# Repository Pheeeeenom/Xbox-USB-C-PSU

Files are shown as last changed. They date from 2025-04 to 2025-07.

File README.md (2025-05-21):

# Xbox-USB-C-PSU
The first ever USB C PSU for the original Xbox

# NOTE:
This board currently supports all 3 Xbox motherboard revisions, but requires a different BOM for 009 and 012 than 121.
If you don't know what revision your Xbox is, you can find out with this guide: [https://www.herringhardware.com/xboxrevisions](https://www.herringhardware.com/XboxRevisions.html)

# REPO STRUCTURE:
All source files for the PCB are contained within the respective folder for each of the 3 official Xbox PCB revions,
-121 to start with, and -009 and -012 will be added soon.
Production files to manufacture the PCBs are located in [Releases](https://github.com/Redherring32/Xbox-USB-C-PSU/releases)

# PCB SPECS:
* 4 layers
* 151.739x39.78mm
* 1oz copper (all layers), heat issues may result from skimping on this
* filled vias (VIPPO) for assembly reasons due to via in pad

kicad_rvZLV58yR5

## LICENSE:
Licensed under
the TAPR Open hardware license (www.tapr.org/OHL)

©Redherring32 2025

## DISCLAIMER:
I offer this with no warranty, express or implied, and I am NOT responsible for anything that may happen as a result of misuse of this PCB.
You have been warned.

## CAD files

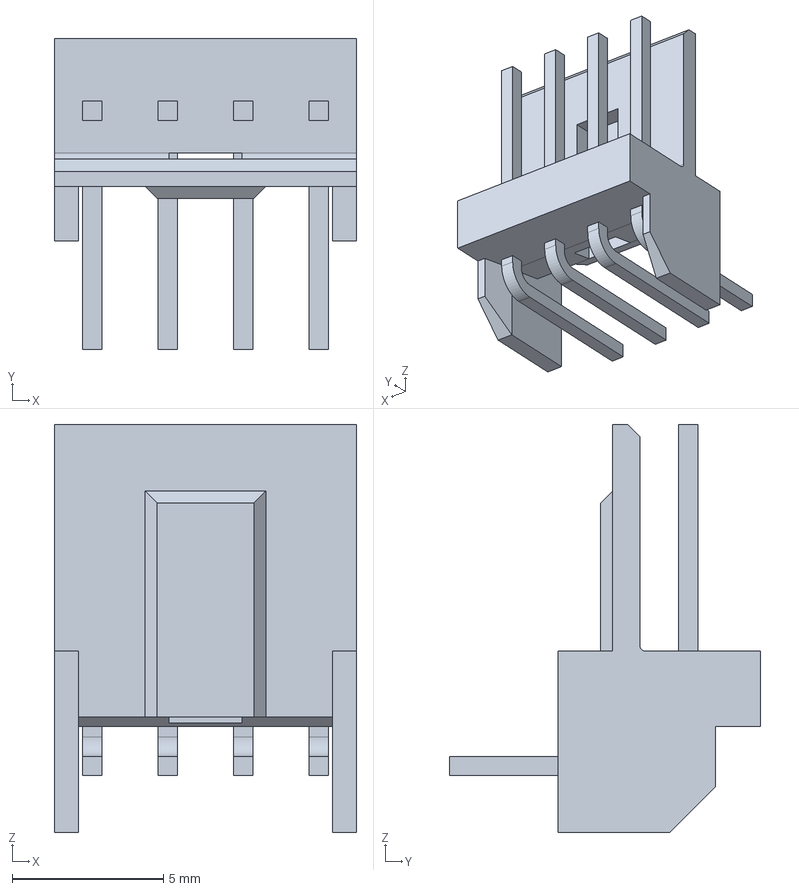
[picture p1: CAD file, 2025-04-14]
-009_012/3D/c-171826-4-y3-3d.stp
10.0 x 10.3 x 13.5 mm

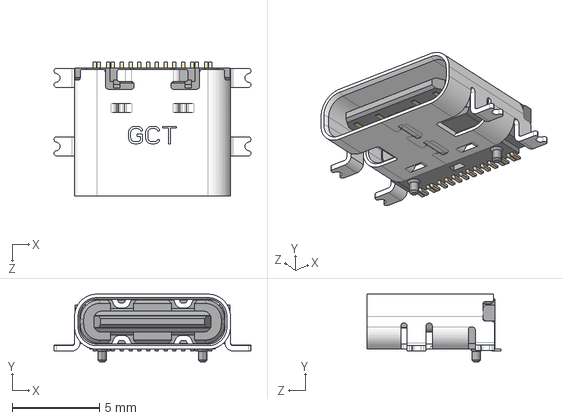
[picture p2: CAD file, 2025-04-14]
-009_012/3D/USB4110GFA.step
11.3 x 3.89 x 7.70 mm

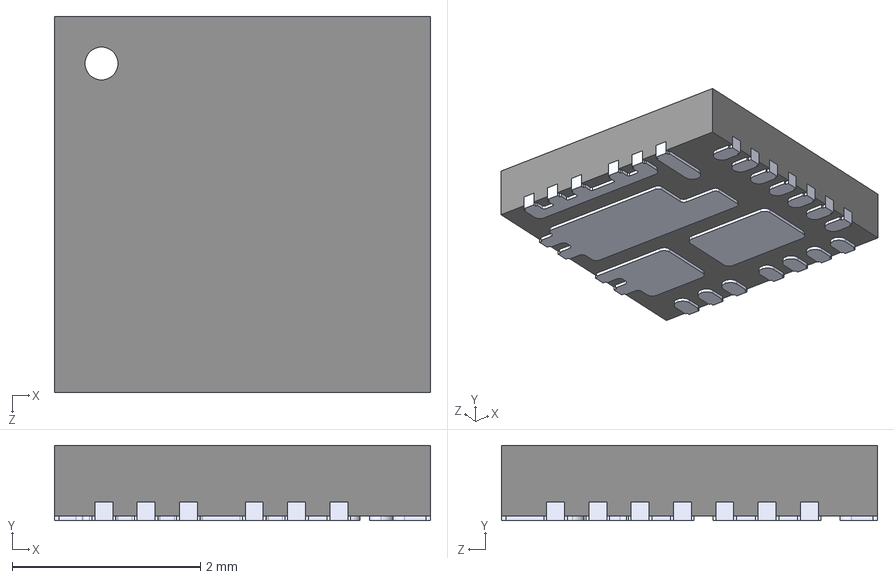
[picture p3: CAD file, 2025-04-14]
-009_012/3D/SIC437BED-T1-GE3.STEP
4.00 x 0.8 x 4.00 mm

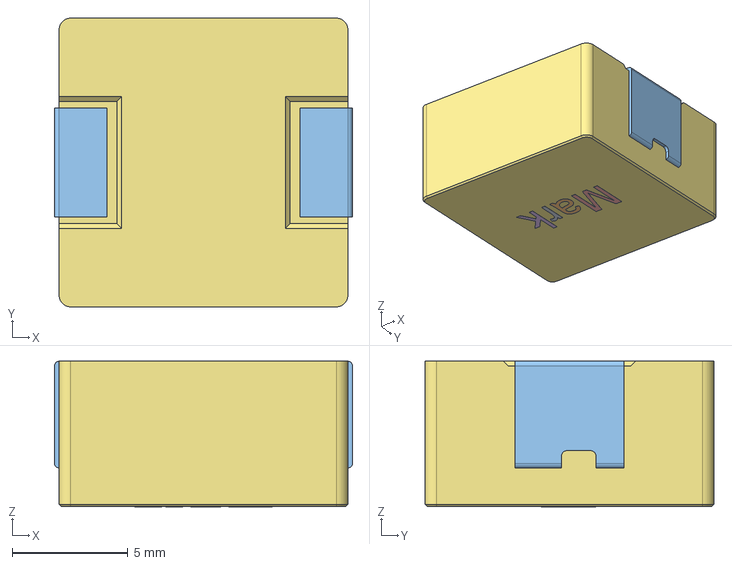
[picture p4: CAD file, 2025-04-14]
-009_012/3D/SRP1265A series.stp
12.9 x 12.5 x 6.30 mm

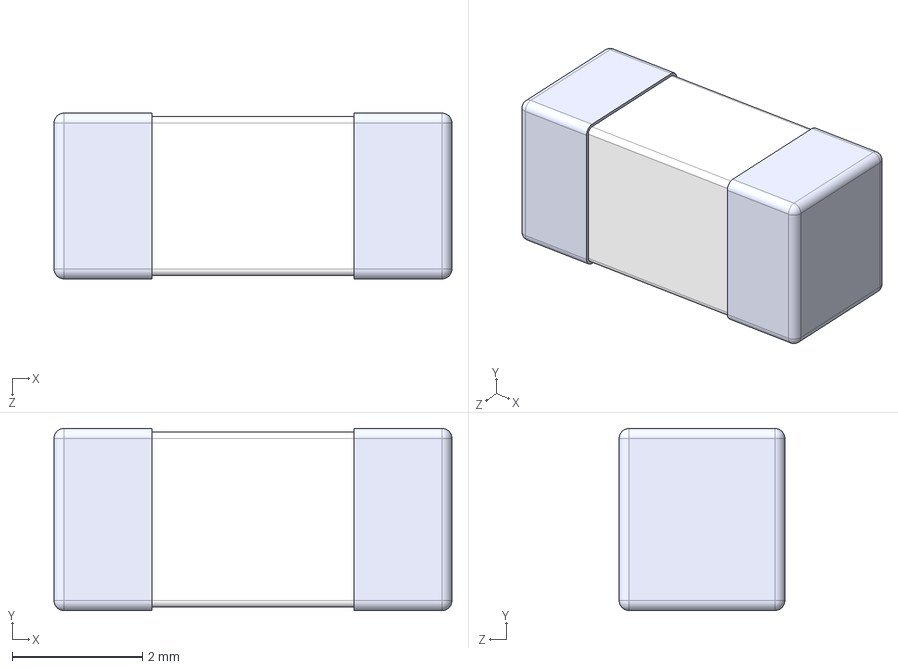
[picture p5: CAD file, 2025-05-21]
-009_012/3D/0679H5000-01.stp
6.10 x 2.79 x 2.54 mm

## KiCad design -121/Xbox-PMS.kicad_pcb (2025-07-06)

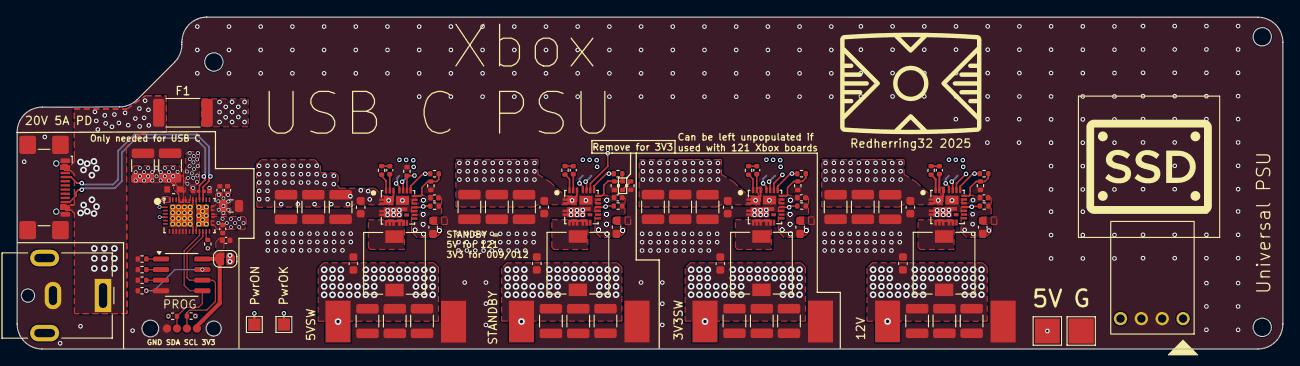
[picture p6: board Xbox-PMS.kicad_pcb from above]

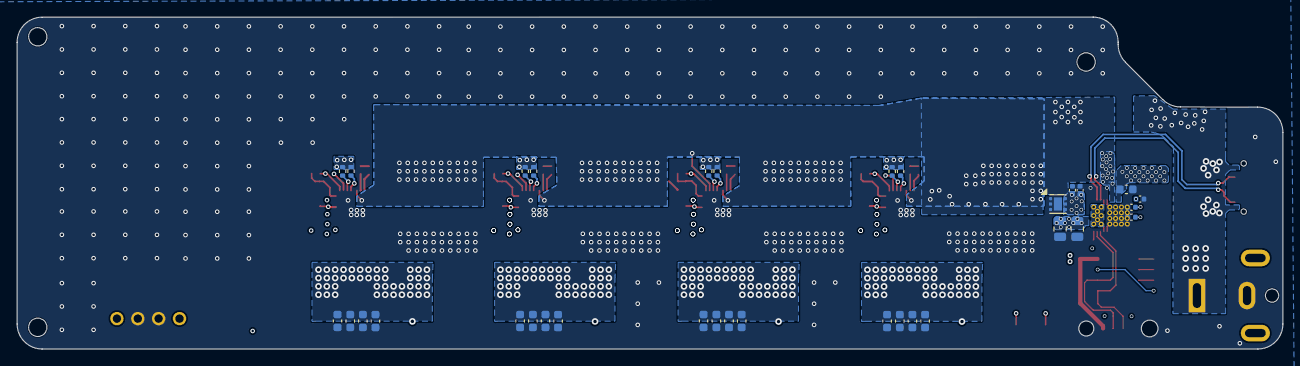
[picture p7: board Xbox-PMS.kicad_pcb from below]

Board: 4 copper layers, 151.7 x 39.8 mm, 139 parts (33 on the bottom side), 55 nets.

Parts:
C1, C2, C3, C4, C5, C6, C8, C10, C11, C64, C65, C66: 22uF; C_1210_3225Metric
C7, C9, C13, C30, C31, C33, C34, C35, C36, C37, C38, C39, C40, C41, C44, C67, C74, C75, C76, C77: 22uF; C_0603_1608Metric
C12, C14, C16, C68: 1uF; C_0402_1005Metric
C15, C17, C18, C69: 4.7uF; C_0603_1608Metric
C19, C20, C22, C60, C70: 0.1uF; C_0402_1005Metric
C21, C23, C24, C25, C26, C27, C28, C29, C32, C71, C72, C73: 47uF; C_1210_3225Metric
C42, C43, C45, C78: 0.1uF; C_0603_1608Metric
C46, C49: 100uF 16V; C_1210_3225Metric
C47: 4.7uF 50V; C_0805_2012Metric
C48, C50, C52, C54, C61: 0.1uF 50V; C_0402_1005Metric
C51, C53: 10uF 16V; C_0603_1608Metric
C55, C56, C57: 10uF 16V; C_0402_1005Metric
C58, C59: 22uF 50V; C_0805_2012Metric
C62, C63: 330pF 16V; C_0201_0603Metric
F1: Fuse 5A; Fuse_2512_6332Metric
IC1, IC2, IC3, IC4: SIC437BED-T1-GE3; SIC437BEDT1GE3
J2: USB_C_Receptacle_USB2.0_16P; USB_C_Receptacle_GCT_USB4110
J3: Jack-DC; BarrelJack_CUI_PJ-063AH_Horizontal
J6: Conn_01x04_Pin; PROG
J7: Conn_01x04_Pin; FDD Connector
J8, J9: Conn_01x01_Pin; TestPoint_Pad_1.5x1.5mm
JP1: Jumper_2_Open; SolderJumper-2_P1.3mm_Open_RoundedPad1.0x1.5mm
L1, L3: 780nH; L_7.3x7.3_H4.5
L2, L4: 820nH; L_7.3x7.3_H4.5
R1, R2, R7, R10, R11, R12, R21, R24, R25, R26, R27: 10K; R_0402_1005Metric
R3, R5, R8, R28: 100K; R_0402_1005Metric
R4, R6, R9, R29: 499K; R_0402_1005Metric
R13, R16, R19, R31: 2.2R; R_0402_1005Metric
R14: 45K; R_0402_1005Metric
R15, R18: 4.12K; R_0402_1005Metric
R17, R20: 18.7K; R_0402_1005Metric
R22, R23: 2.2K; R_0402_1005Metric
R30: 430R; R_0402_1005Metric
R32: 8.2K; R_0402_1005Metric
R35: 6.8K; R_0402_1005Metric
R36: 0; R_0402_1005Metric
TP3, TP4, TP5, TP6, TP7, TP8, TP9, TP10: TestPoint; pad
U1: TVS2200DRV; WSON-6-1EP_2x2mm_P0.65mm_EP1x1.6mm
U2: TPS25750; TPS25750D
U3: CAT24C512; SOIC-8_3.9x4.9mm_P1.27mm

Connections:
/3V3: C57.1, U2.38 (VIN_3V3)
/3V3SB: C23.2, C25.1, C28.1, C31.1, C34.1, C37.1, C40.1, C43.1, IC1.18 (VOUT), L2.2, R17.1, TP5.1
/3V3SW: C21.2, C24.1, C27.1, C30.1, C33.1, C36.1, C39.1, C42.1, IC2.18 (VOUT), L1.2, R14.1, TP3.1
/5VSW: C26.2, C29.1, C32.1, C35.1, C38.1, C41.1, C44.1, C45.1, IC3.18 (VOUT), J7.4, L3.2, R20.1, TP7.1
/12V: C71.2, C72.1, C73.1, C74.1, C75.1, C76.1, C77.1, C78.1, IC4.18 (VOUT), J7.1, L4.2, R32.1, TP9.1
/CCx+: C63.1, J2.A5 (CC1), U2.28 (CC1)
/CCx-: C62.1, J2.B5 (CC2), U2.29 (CC2)
/DRAIN: U2.15 (DRAIN), U2.30 (DRAIN), U2.40 (DRAIN_PAD)
/EEPROM_3V3: C60.1, J6.4, JP1.1 (A), U3.8 (VCC)
/EN: IC2.19 (EN), IC3.19 (EN), IC4.19 (EN), J9.1, R11.1
/LDO_1V5: C56.1, U2.4 (LDO_1V5)
/LDO_3V3: C55.1, JP1.2 (B), R21.2, R22.2, R23.2, U2.1 (LDO_3V3)
/PGOOD: IC1.14 (P_GOOD), IC2.14 (P_GOOD), IC3.14 (P_GOOD), IC4.14 (P_GOOD), J8.1, R1.1, R2.1, R7.1, R10.1
/PP5V: C46.1, C49.1, C51.1, C53.1, U2.34 (PP5V), U2.35 (PP5V)
/PPHV: C58.1, C59.1, C61.1, U2.20 (PPHV), U2.21 (PPHV), U2.22 (PPHV)
/SCL: J6.3, R23.1, U2.17 (I2Cm_SCL), U3.6 (SCL)
/SDA: J6.2, R22.1, U2.16 (I2Cm_SDA), U3.5 (SDA)
/VBUS-IN: F1.1, J2.A4 (VBUS), J2.A9 (VBUS), J2.B4 (VBUS), J2.B9 (VBUS), J3.1
/VBUS-SAFE: C1.1, C2.1, C3.1, C4.1, C5.1, C6.1, C7.1, C8.1, C9.1, C10.1, C11.1, C13.1, C47.1, C48.1, C50.1, C52.1, C54.1, C64.1, C65.1, C66.1, C67.1, F1.2, IC1.1 (VIN), IC1.2 (VIN), IC1.19 (EN), IC1.22 (VIN), IC1.26 (VIN), IC2.1 (VIN), IC2.2 (VIN), IC2.22 (VIN), IC2.26 (VIN), IC3.1 (VIN), IC3.2 (VIN), IC3.22 (VIN), IC3.26 (VIN), IC4.1 (VIN), IC4.2 (VIN), IC4.22 (VIN), IC4.26 (VIN), U1.4 (IN), U1.5 (IN), U1.6 (IN), U2.23 (VBUS_IN), U2.24 (VBUS_IN), U2.25 (VBUS_IN), U2.32 (VBUS), U2.33 (VBUS)
/VDD: C12.2, C14.2, C15.2, C16.2, C17.2, C18.2, C68.2, C69.2, IC1.12 (V_DRV), IC1.15 (VDD), IC2.12 (V_DRV), IC2.15 (VDD), IC3.12 (V_DRV), IC3.15 (VDD), IC4.12 (V_DRV), IC4.15 (VDD), R1.2, R2.2, R3.2, R4.1, R5.2, R6.1, R7.2, R8.2, R9.1, R10.2, R28.2, R29.1
/~IRQ: R21.1, U2.18 (I2Cm_IRQ_N)
GND: C1.2, C2.2, C3.2, C4.2, C5.2, C6.2, C7.2, C8.2, C9.2, C10.2, C11.2, C12.1, C13.2, C14.1, C15.1, C16.1, C17.1, C18.1, C21.1, C23.1, C24.2, C25.2, C26.1, C27.2, C28.2, C29.2, C30.2, C31.2, C32.2, C33.2, C34.2, C35.2, C36.2, C37.2, C38.2, C39.2, C40.2, C41.2, C42.2, C43.2, C44.2, C45.2, C46.2, C47.2, C48.2, C49.2, C50.2, C51.2, C52.2, C53.2, C54.2, C55.2, C56.2, C57.2, C58.2, C59.2, C60.2, C61.2, C62.2, C63.2, C64.2, C65.2, C66.2, C67.2, C68.1, C69.1, C71.1, C72.2, C73.2, C74.2, C75.2, C76.2, C77.2, C78.2, IC1.3 (PGND), IC1.4 (PGND), IC1.13 (PGND), IC1.16 (AGND), IC1.25 (AGND), IC1.27 (PGND), IC1.29 (PGND), IC2.3 (PGND), IC2.4 (PGND), IC2.13 (PGND), IC2.16 (AGND), IC2.25 (AGND), IC2.27 (PGND), IC2.29 (PGND), IC3.3 (PGND), IC3.4 (PGND), IC3.13 (PGND), IC3.16 (AGND), IC3.25 (AGND), IC3.27 (PGND), IC3.29 (PGND), IC4.3 (PGND), IC4.4 (PGND), IC4.13 (PGND), IC4.16 (AGND), IC4.25 (AGND), IC4.27 (PGND), IC4.29 (PGND), J2.A1 (GND), J2.A12 (GND), J2.B1 (GND), J2.B12 (GND), J2.S1 (SHIELD), J3.2, J6.1, J7.2, J7.3, R11.2, R12.2, R15.2, R18.2, R24.2, R25.2, R26.2, R27.2, R30.2, R35.2, TP4.1, TP6.1, TP8.1, TP10.1, U1.1 (GND), U1.2 (GND), U1.3 (GND), U1.7 (GND), U2.8 (I2Cs_SDA), U2.9 (I2Cs_SCL), U2.10 (I2Cs_IRQ_N), U2.11 (GND), U2.12 (GND), U2.14 (GND), U2.31 (GND), U2.39 (GND_PAD), U3.4 (GND)
unnamed: C19.2, R13.2
unnamed: C20.2, R16.2
unnamed: C22.2, R19.2
unnamed: C70.2, R31.2
unnamed: C20.1, IC1.23 (BOOT)
unnamed: IC1.17 (FB), R15.1, R17.2
unnamed: IC1.21 (MODE1), R5.1
unnamed: IC1.20 (MODE2), R6.2
unnamed: IC1.24 (PHASE), R16.1
unnamed: IC1.5 (SW), IC1.6 (SW), IC1.7 (SW), IC1.8 (SW), IC1.9 (SW), IC1.30 (SW), L2.1
unnamed: C19.1, IC2.23 (BOOT)
unnamed: IC2.17 (FB), R12.1, R14.2
unnamed: IC2.21 (MODE1), R3.1
unnamed: IC2.20 (MODE2), R4.2
unnamed: IC2.24 (PHASE), R13.1
unnamed: IC2.5 (SW), IC2.6 (SW), IC2.7 (SW), IC2.8 (SW), IC2.9 (SW), IC2.30 (SW), L1.1
unnamed: C22.1, IC3.23 (BOOT)
unnamed: IC3.17 (FB), R18.1, R20.2, R36.1
unnamed: IC3.21 (MODE1), R8.1
unnamed: IC3.20 (MODE2), R9.2
unnamed: IC3.24 (PHASE), R19.1
unnamed: IC3.5 (SW), IC3.6 (SW), IC3.7 (SW), IC3.8 (SW), IC3.9 (SW), IC3.30 (SW), L3.1
unnamed: C70.1, IC4.23 (BOOT)
unnamed: IC4.17 (FB), R30.1, R32.2
unnamed: IC4.21 (MODE1), R28.1
unnamed: IC4.20 (MODE2), R29.2
unnamed: IC4.24 (PHASE), R31.1
unnamed: IC4.5 (SW), IC4.6 (SW), IC4.7 (SW), IC4.8 (SW), IC4.9 (SW), IC4.30 (SW), L4.1
unnamed: R35.1, R36.2
unnamed: R24.1, U3.1 (A0)
unnamed: R25.1, U3.2 (A1)
unnamed: R26.1, U3.3 (A2)
unnamed: R27.1, U3.7 (WP)

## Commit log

2025-04-14 Add -121 Files
    [SIC437BED-T1-GE3.STEP, SRP1265A series.stp, USB4110GFA.step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]
2025-04-15 * Enlarge Pin 1 markers * Clean up zone outlines
    [Xbox-PMS.kicad_pcb]
2025-05-21 + Update design to Universal, 1 PCB covers all 3 Xbox Motherboard Revisions now. + Clean up schematic refdes + Clean up zone outlines + Add 009/012 schematic
    [0679H5000-01.stp, SIC437BED-T1-GE3.STEP, SRP1265A series.stp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]
2025-05-21 Update PCB image, Update PCB dimensions.
2025-07-05 Fix value of R15 in -009_012 schematic
    [Xbox-PMS.kicad_sch]
2025-07-06 Add jumper 0ohm
    configurable STANDBY voltage.
    update silkscreen
    [Xbox-PMS.kicad_pcb, Xbox-PMS.kicad_sch]
